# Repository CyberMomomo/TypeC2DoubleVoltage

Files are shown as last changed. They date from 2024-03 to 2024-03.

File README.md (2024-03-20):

# TypeC2DoubleVoltage
>
> ## Introduction
>
> This device is used for converting voltage from 5V input by USB Type-C Plug to any positive and negetive voltages from 1.25V to 30V.

> ## How to use
>
> Use the gerber files and bom from releases you could get a demo board which can produce +12V 40mA and -12V 40mA output. By changing R7, R8, R11, R14 you could get any other voltages you want. But you should use proper capacitors when you use the device to get other voltages in order to avoid the overvoltage. And any sigle volatge output should not load over 500mW or the output ripple will surge and the MC34063 may overheat.

> ## Performance
>
> For the demo board, the output ripple is lower than 1mVpp in unloaded test, and it is lower than 2mVpp when loading a 40mA output.

> ## Images
>
> 
> 
> 
>

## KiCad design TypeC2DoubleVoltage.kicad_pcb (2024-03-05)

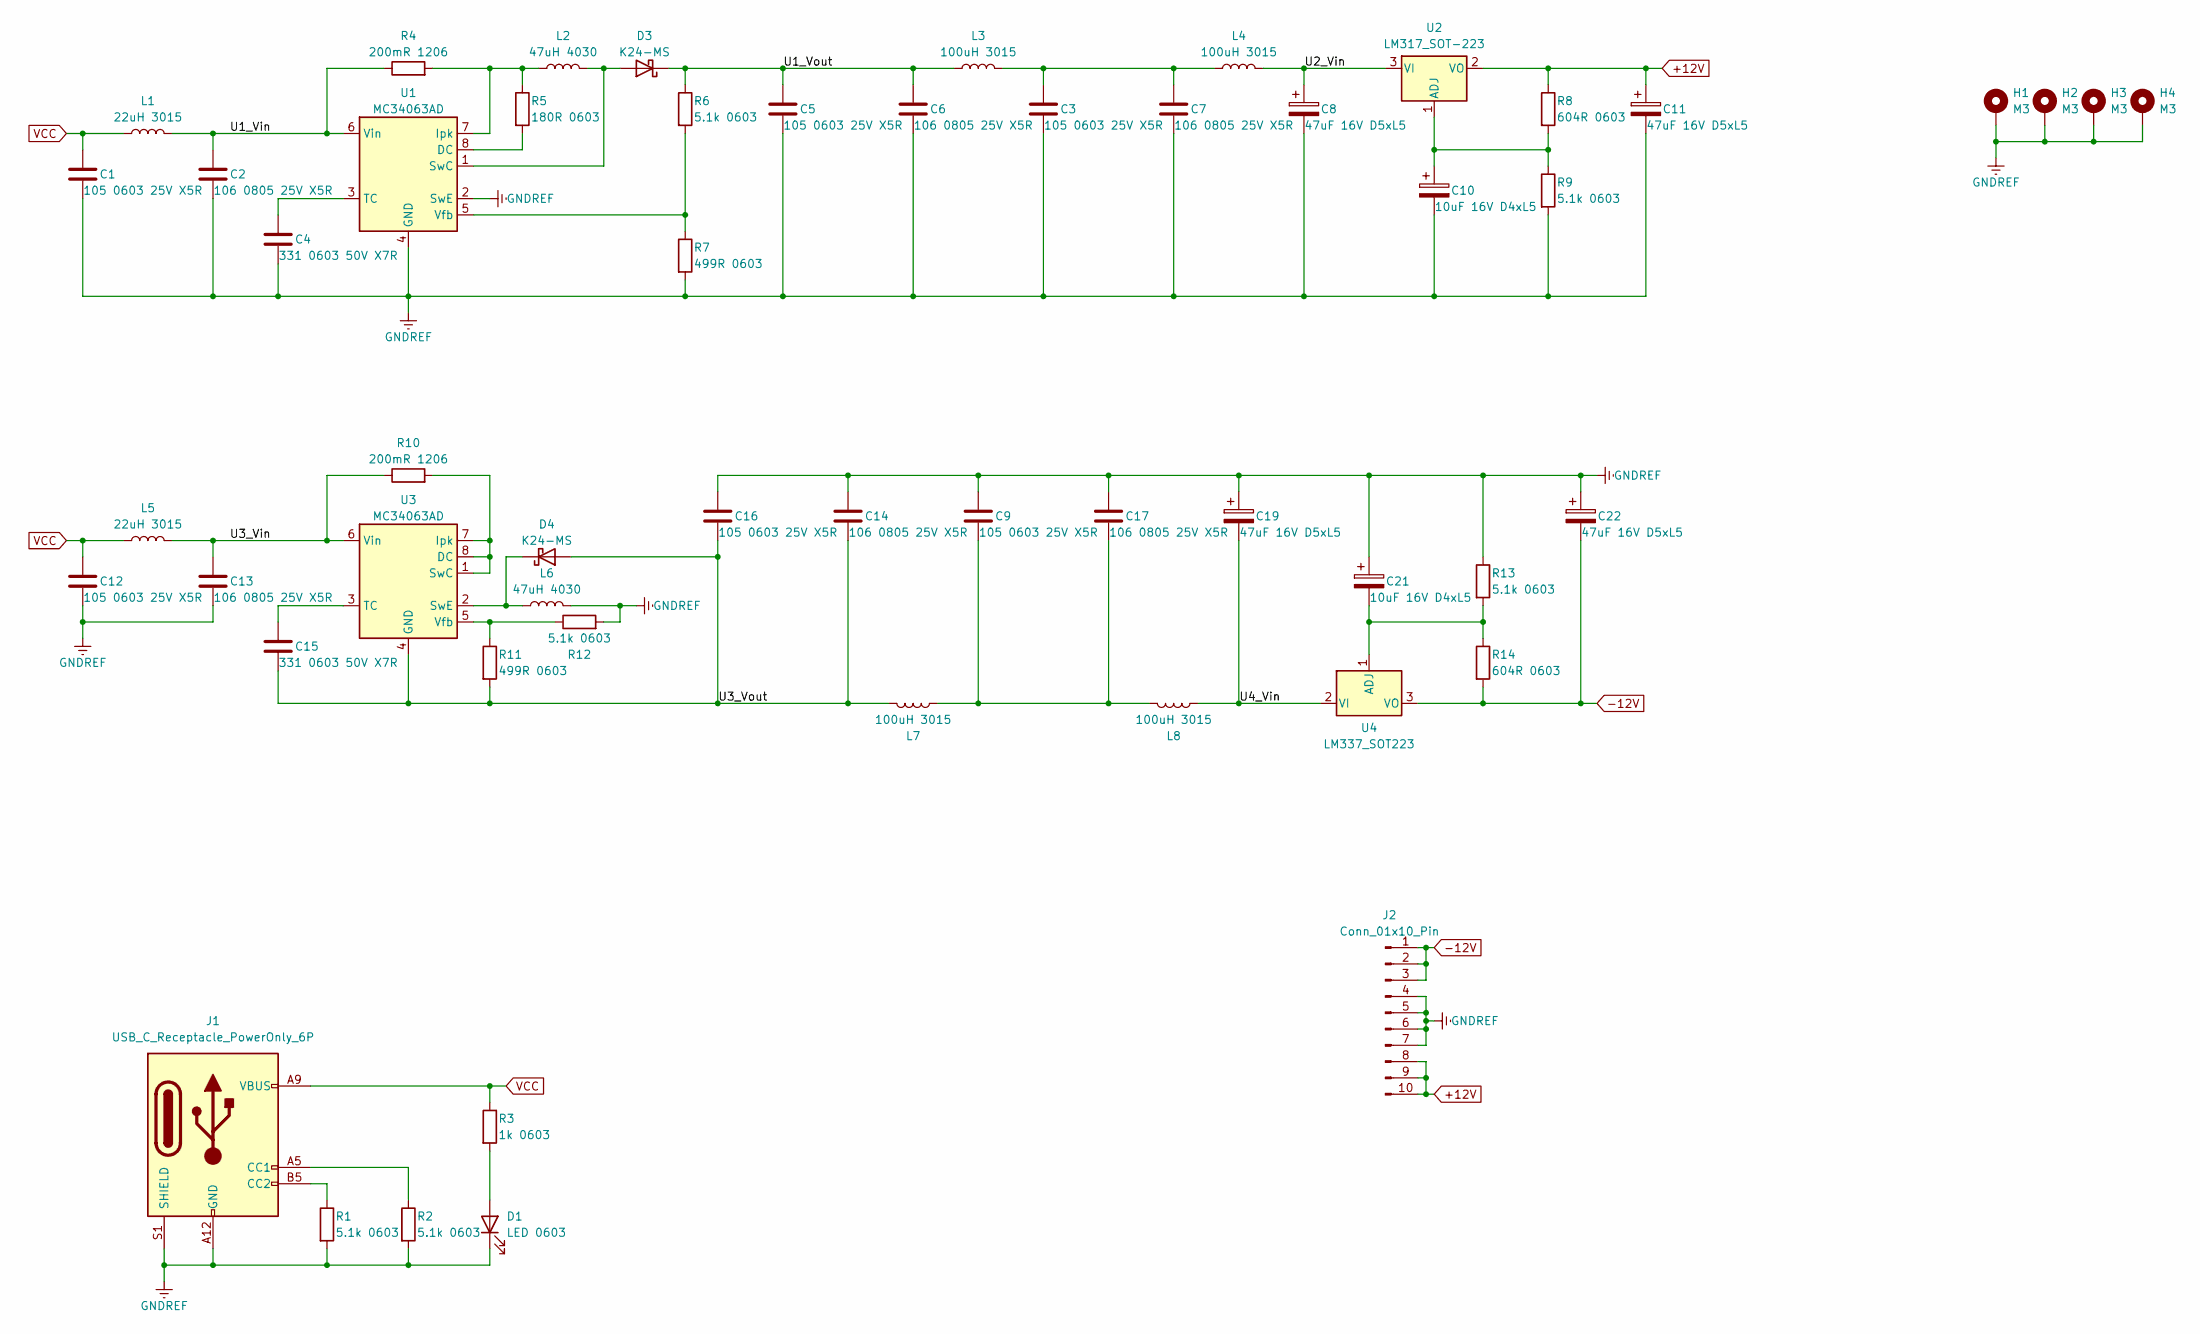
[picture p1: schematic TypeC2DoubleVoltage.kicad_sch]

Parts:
C1, C3, C5, C9, C12, C16: 105 0603 25V X5R; C_0603_1608Metric
C2, C6, C7, C13, C14, C17: 106 0805 25V X5R; C_0805_2012Metric
C4, C15: 331 0603 50V X7R; C_0603_1608Metric
C8, C11, C19, C22: 47uF 16V D5xL5; CP_Radial_D5.0mm_P2.00mm
C10, C21: 10uF 16V D4xL5; CP_Radial_D4.0mm_P1.50mm
D1: LED 0603; LED_0603_1608Metric
D3, D4: K24-MS; D_SOD-123F
H1, H2, H3, H4: M3; MountingHole_3.2mm_M3_Pad
J1: USB_C_Receptacle_PowerOnly_6P; USB_C_Receptacle_6P_01
J2: Conn_01x10_Pin; PinHeader_1x10_P2.54mm_Vertical
L1, L5: 22uH 3015; L_Changjiang_FNR3015S
L2, L6: 47uH 4030; L_Changjiang_FNR4030S
L3, L4, L7, L8: 100uH 3015; L_Changjiang_FNR3015S
R1, R2, R6, R9, R12, R13: 5.1k 0603; R_0603_1608Metric
R3: 1k 0603; R_0603_1608Metric
R4, R10: 200mR 1206; R_1206_3216Metric
R5: 180R 0603; R_0603_1608Metric
R7, R11: 499R 0603; R_0603_1608Metric
R8, R14: 604R 0603; R_0603_1608Metric
U1, U3: MC34063AD; SOIC-8_3.9x4.9mm_P1.27mm
U2: LM317_SOT-223; SOT-223-3_TabPin2
U4: LM337_SOT223; SOT-223-3_TabPin2

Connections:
+12V: C11.1, J2.8, J2.9, J2.10, R8.1, U2.2 (VO)
-12V: C22.2, J2.1, J2.2, J2.3, R14.2, U4.3 (VO)
/U1_Vin: C2.2, L1.2, R4.1, U1.6 (Vin)
/U1_Vout: C5.2, C6.2, D3.1 (K), L3.1, R6.1
/U2_Vin: C8.1, L4.2, U2.3 (VI)
/U3_Vin: C13.2, L5.2, R10.1, U3.6 (Vin)
/U3_Vout: C14.1, C15.1, C16.1, D4.2 (A), L7.1, R11.2, U3.4 (GND)
/U4_Vin: C19.2, L8.2, U4.2 (VI)
GNDREF: C1.1, C2.1, C3.1, C4.1, C5.1, C6.1, C7.1, C8.2, C9.2, C10.2, C11.2, C12.1, C13.1, C14.2, C16.2, C17.2, C19.1, C21.1, C22.1, D1.1 (K), H1.1, H2.1, H3.1, H4.1, J1.A12 (GND), J1.B12 (GND), J1.S1 (SHIELD), J2.4, J2.5, J2.6, J2.7, L6.2, R1.2, R2.2, R7.2, R9.2, R12.2, R13.1, U1.2 (SwE), U1.4 (GND)
unnamed: C3.2, C7.2, L3.2, L4.1
unnamed: C9.1, C17.1, L7.2, L8.1
unnamed: D1.2 (A), R3.2
unnamed: D3.2 (A), L2.2, U1.1 (SwC)
unnamed: D4.1 (K), L6.1, U3.2 (SwE)
unnamed: J1.A5 (CC1), R2.1
unnamed: J1.B5 (CC2), R1.1
unnamed: R5.2, U1.8 (DC)
unnamed: L2.1, R4.2, R5.1, U1.7 (Ipk)
unnamed: C4.2, U1.3 (TC)
unnamed: R6.2, R7.1, U1.5 (Vfb)
unnamed: C10.1, R8.2, R9.1, U2.1 (ADJ)
unnamed: R10.2, U3.1 (SwC), U3.7 (Ipk), U3.8 (DC)
unnamed: C15.2, U3.3 (TC)
unnamed: R11.1, R12.1, U3.5 (Vfb)
unnamed: C21.2, R13.2, R14.1, U4.1 (ADJ)
VCC: C1.2, C12.2, J1.A9 (VBUS), J1.B9 (VBUS), L1.1, L5.1, R3.1

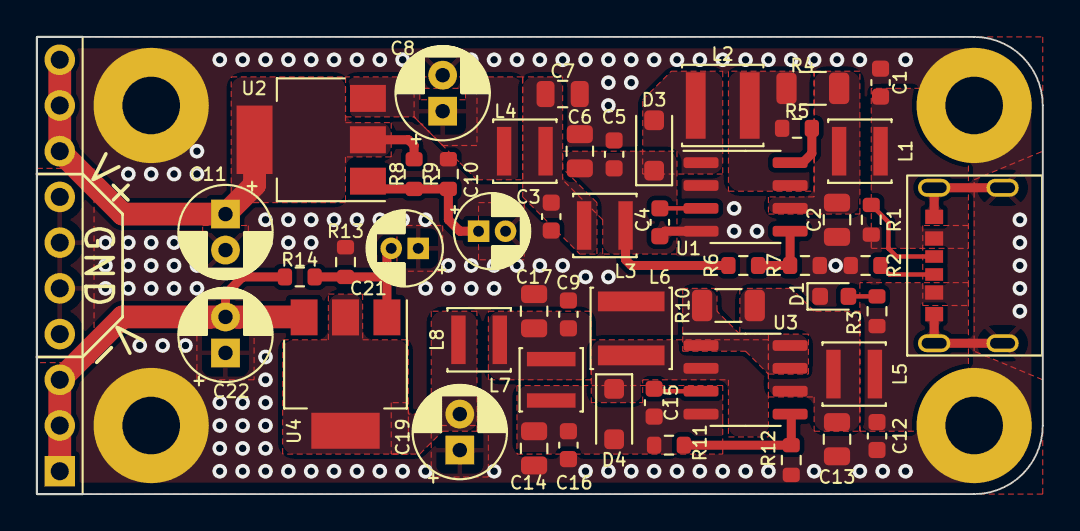
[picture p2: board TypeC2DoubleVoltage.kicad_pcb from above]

Board: 2 copper layers, 55.9 x 25.4 mm, 55 parts (0 on the bottom side), 26 nets.

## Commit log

2024-02-06 Create Project
    [TypeC2DoubleVoltage.kicad_pcb, TypeC2DoubleVoltage.kicad_sch]
2024-02-06 Almost Finish
    [TypeC2DoubleVoltage.kicad_pcb, TypeC2DoubleVoltage.kicad_sch]
